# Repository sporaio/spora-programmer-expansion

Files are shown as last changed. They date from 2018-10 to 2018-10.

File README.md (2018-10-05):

# Spora Programmer Expansion

This is the repository of the Spora Programmer Expansion. Spora is coin-sized open source programmable board, equipped with multiple sensors, a powerful MCU and Bluetooth module to transmit your collected data.

With this board you can expand Spora's functioanlity into anything you want. Find out more about Spora at https://sporaio.com/

Spora's main board code is in this repository: https://github.com/sporaio/spora-board

## Contributors

This project is open source, under the BSD licence. You can contribute to it and be part of this great community.

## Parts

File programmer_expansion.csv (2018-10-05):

Refs | Desc | datasheet | digikey# | footprint | manf | manf# | value
C1 | 10uF 10% 16V Ceramic Capacitor X5R 0805 |  | 490-6473-1-ND | footprints:c_0805 | Murata Electronics North America | GRM21BR61C106KE15K | 10uF
C2 | 10uF 10% 16V Ceramic Capacitor X5R 0805 |  | 490-6473-1-ND | footprints:c_0805 | Murata Electronics North America | GRM21BR61C106KE15K | 10uF
C3 | 10uF 10% 16V Ceramic Capacitor X5R 0805 |  | 490-6473-1-ND | footprints:c_0805 | Murata Electronics North America | GRM21BR61C106KE15K | 10uF
C4 | 10uF 10% 16V Ceramic Capacitor X5R 0805 |  | 490-6473-1-ND | footprints:c_0805 | Murata Electronics North America | GRM21BR61C106KE15K | 10uF
C5 | 10uF 10% 16V Ceramic Capacitor X5R 0805 |  | 490-6473-1-ND | footprints:c_0805 | Murata Electronics North America | GRM21BR61C106KE15K | 10uF
C6 | 10uF 10% 16V Ceramic Capacitor X5R 0805 |  | 490-6473-1-ND | footprints:c_0805 | Murata Electronics North America | GRM21BR61C106KE15K | 10uF
C7 | 0.10uF 10% 16V Ceramic Capacitor X7R 0805 |  | 490-1683-1-ND | footprints:c_0805 | Murata Electronics North America | GRM219R71C104KA01D | 0.1uF
CON1 | Power Barrel Connector Jack 0.70mm ID (0.028), 2.35mm OD (0.093) EIAJ-1 Surface Mount, Right Angle |  | CP-038PJCT-ND | footprints:Pj-38-smt | CUI Inc. | PJ-038-SMT-TR | BARREL_JACK
CON2 | Pad de coneccion para una eventual bateria |  |  | footprints:GS2 |  |  | TP1
CON3 | 10 Positions Header, Unshrouded Connector 0.100 (2.54mm) Through Hole Tin |  | 609-3243-ND | Pin_Headers:Pin_Header_Straight_2x05 | Amphenol FCI | 67997-410HLF | SWD_BT
CON4 | 10 Positions Header, Unshrouded Connector 0.100 (2.54mm) Through Hole Tin |  | 609-3243-ND | Pin_Headers:Pin_Header_Straight_2x05 | Amphenol FCI | 67997-410HLF | SWD_MCU
D1 | Red 645nm LED Indication - Discrete 1.8V 0805 (2012 Metric) |  | 475-1415-1-ND | footprints:LED-0805 | OSRAM Opto Semiconductors Inc. | LH R974-LP-1 | Led
D2 | Red 645nm LED Indication - Discrete 1.8V 0805 (2012 Metric) |  | 475-1415-1-ND | footprints:LED-0805 | OSRAM Opto Semiconductors Inc. | LH R974-LP-1 | Led
G1 | Logo INTI |  |  | footprints:LOGO_INTI |  |  | LOGO_INTI
J1 | 10 Position Connector Receptacle, Center Strip Contacts Surface Mount Gold |  | H11719CT-ND | footprints:df12(3.0)-10ds-0.5v | Hirose Electric Co Ltd | DF12B3.0-10DS-0.5V86 | DF12B-3.0-10DS-0.5V-81
R1 | RES SMD 270 OHM 1% 1/8W 0805 |  | 311-270CRCT-ND | footprints:r_0805 | Yageo | RC0805FR-07270RL | 270
R2 | RES SMD 470 OHM 1% 1/8W 0805 |  | 311-470CRCT-ND | footprints:r_0805 | Yageo | RC0805FR-07470RL | 470
R3 | RES SMD 1.2K OHM 1% 1/8W 0805 |  | 311-1.20KCRCT-ND | footprints:r_0805 | Yageo | RC0805FR-071K2L | 1,2k
R4 | RES SMD 280 OHM 1% 1/8W 0805 |  | 311-280CRCT-ND | footprints:r_0805 | Yageo | RC0805FR-07280RL | 280
R5 | RES SMD 10K OHM 5% 1/4W 0805 |  | RPC0805JT10K0DKR-ND | footprints:r_0805 | Stackpole Electronics Inc. | RPC0805JT10K0 | 10K
R6 | RES SMD 4.7K OHM 5% 1/2W 0805 |  | P16962CT-ND | footprints:r_0805 | Panasonic Electronic Components | ERJ-P6WJ472V | 4,7K
R7 | RES SMD 4.7K OHM 5% 1/2W 0805 |  | P16962CT-ND | footprints:r_0805 | Panasonic Electronic Components | ERJ-P6WJ472V | 4,7K
R8 | RES SMD 4.7K OHM 5% 1/2W 0805 |  | P16962CT-ND | footprints:r_0805 | Panasonic Electronic Components | ERJ-P6WJ472V | 4K7
SW1 | Tactile Switch SPST-NO Top Actuated Surface Mount |  | SW1143CT-ND | footprints:B3U_1000PB | Omron Electronics Inc-EMC Div | B3U-1000P-B | SIDE_SW
SW2 | Tactile Switch SPST-NO Top Actuated Surface Mount |  | SW1143CT-ND | footprints:B3U_1000PB | Omron Electronics Inc-EMC Div | B3U-1000P-B | SIDE_SW
U1 | Linear Voltage Regulator IC Positive Adjustable 1 Output 1.25 V 13.8 V 800mA SOT-223 |  | LM1117MPX-ADJ/NOPBCT-ND | footprints:sot223 | Texas Instruments | LM1117MPX-ADJ/NOPB | LM1117
U2 | Linear Voltage Regulator IC Positive Adjustable 1 Output 1.25 V 13.8 V 800mA SOT-223 |  | LM1117MPX-ADJ/NOPBCT-ND | footprints:sot223 | Texas Instruments | LM1117MPX-ADJ/NOPB | LM1117
C10 | CAP CER 0.1UF 16V X7R 0805 |  | 490-1683-1-ND | footprints:c_0805 | Murata Electronics North America | GRM219R71C104KA01D | 0.1uF
C11 | CAP CER 0.1UF 16V X7R 0805 |  | 490-1683-1-ND | footprints:c_0805 | Murata Electronics North America | GRM219R71C104KA01D | 0.1uF
C8 | CAP CER 0.1UF 16V X7R 0805 |  | 490-1683-1-ND | footprints:c_0805 | Murata Electronics North America | GRM219R71C104KA01D | 0.1uF
C9 | CAP CER 0.1UF 16V X7R 0805 |  | 490-1683-1-ND | footprints:c_0805 | Murata Electronics North America | GRM219R71C104KA01D | 0.1uF

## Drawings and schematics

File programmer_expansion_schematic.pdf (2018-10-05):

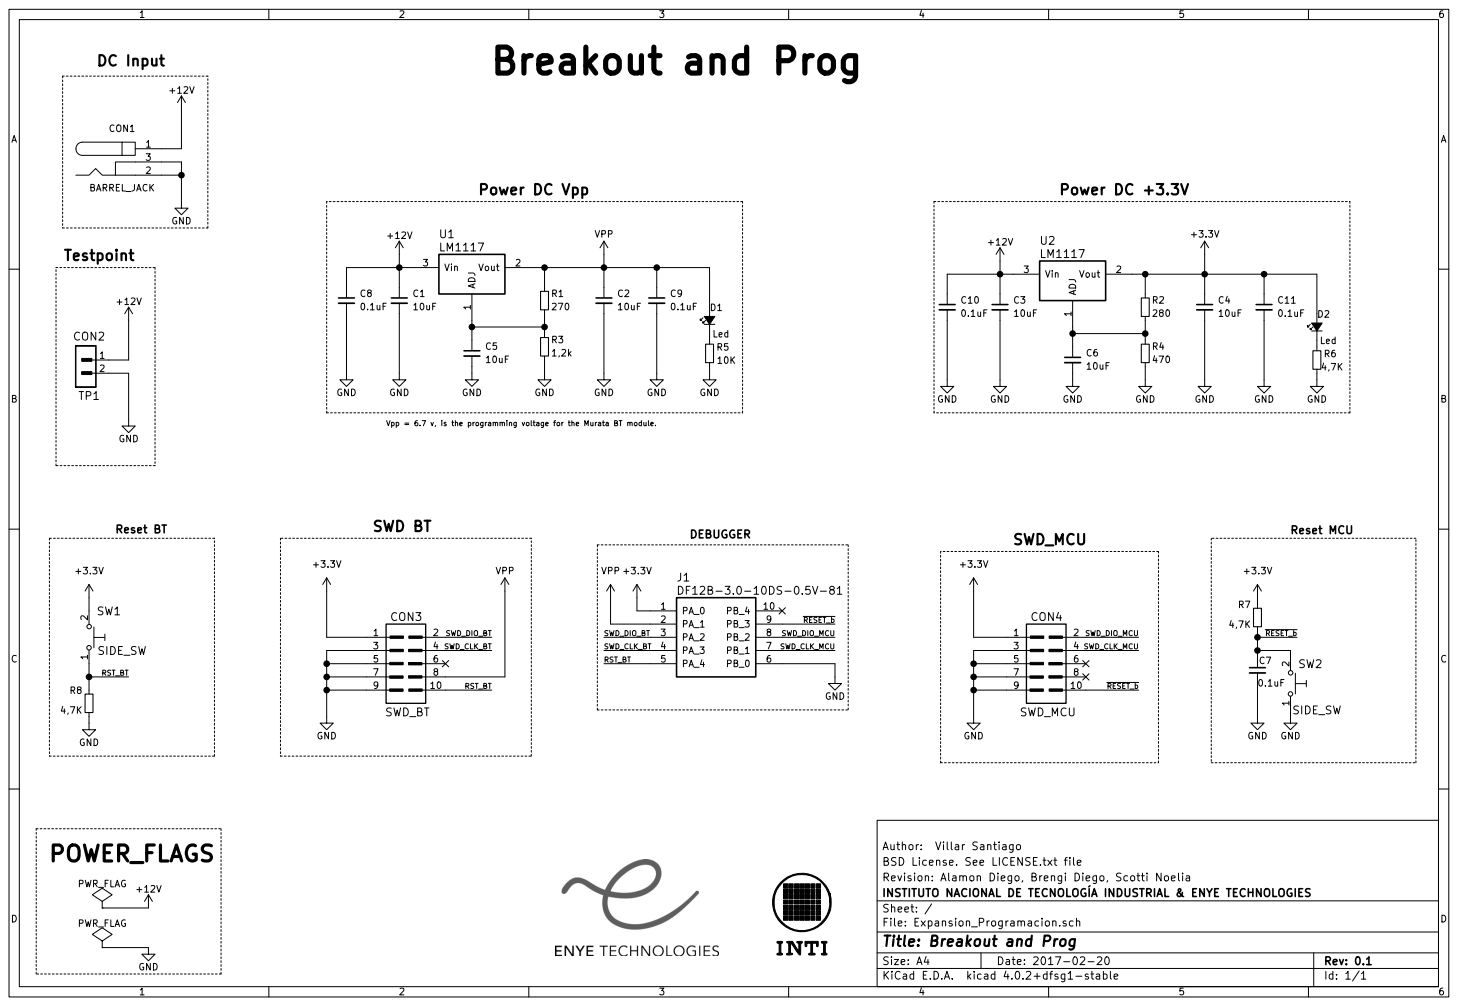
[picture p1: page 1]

3 CON1 BARREL_JACK

Revision: Alamon Diego, Brengi Diego, Scotti Noelia BSD License. See LICENSE.txt file Author: Villar Santiago PWR_FLAG

INSTITUTO NACIONAL DE TECNOLOGÍA INDUSTRIAL & ENYE TECHNOLOGIES
File: Expansion_Programacion.sch Sheet: /
Id: 1/1 Title: Breakout and Prog

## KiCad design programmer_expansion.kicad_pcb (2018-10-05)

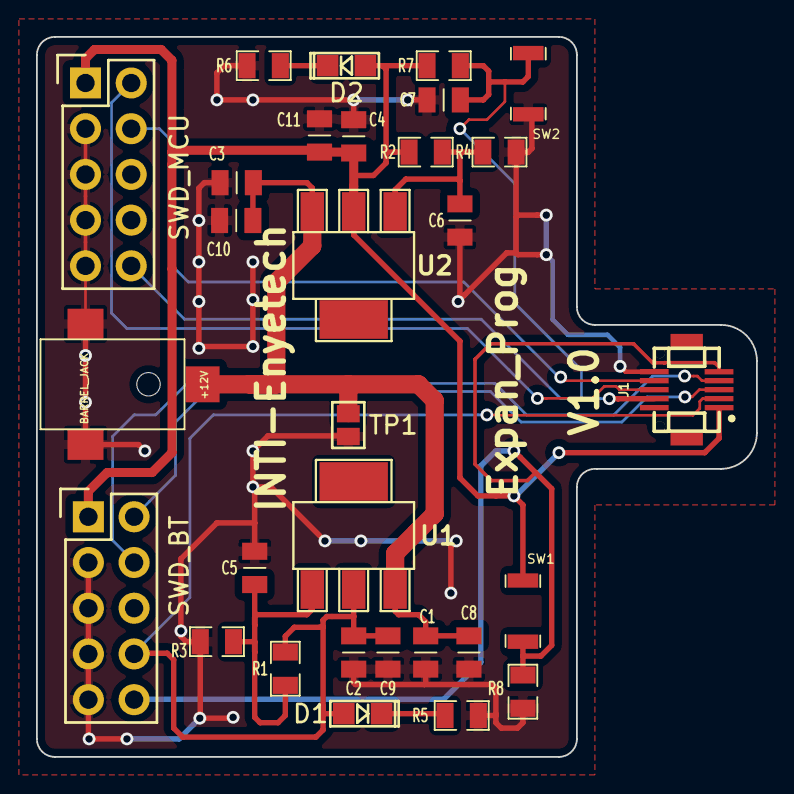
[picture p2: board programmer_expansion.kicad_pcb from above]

Board: 2 copper layers, 40.0 x 40.0 mm, 30 parts (0 on the bottom side), 14 nets.

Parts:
+12V: BARREL_JACK; Pj-38-smt
C1, C2, C3, C4, C5, C6: 10uF; c_0805
C7, C8, C9, C10, C11: 0.1uF; c_0805
D1, D2: Led; LED-0805
J1: DF12B-3.0-10DS-0.5V-81; df12(3.0)-10ds-0.5v
R1: 270; r_0805
R2: 470; r_0805
R3: 1,2k; r_0805
R4: 280; r_0805
R5: 10K; r_0805
R6, R7: 4,7K; r_0805
R8: 4K7; r_0805
SW1, SW2: SIDE_SW; B3U_1000PB
SWD_BT: SWD_BT; Pin_Header_Straight_2x05
SWD_MCU: SWD_MCU; Pin_Header_Straight_2x05
TP1: TP1; GS2
U1, U2: LM1117; sot223

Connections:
+3V3: C4.1, C11.1, D2.2, J1.1, R2.1, R7.2, SW1.2, SWD_BT.1, SWD_MCU.1, U2.2
+12V: +12V.1, C1.1, C3.1, C8.1, C10.1, TP1.1, U1.3, U2.3
/RST_BT: J1.5, R8.2, SW1.1, SWD_BT.10
/SWD_CLK_BT: J1.4, SWD_BT.4
/SWD_CLK_MCU: J1.7, SWD_MCU.4
/SWD_DIO_BT: J1.3, SWD_BT.2
/SWD_DIO_MCU: J1.8, SWD_MCU.2
/~RESET_b: C7.1, J1.9, R7.1, SW2.2, SWD_MCU.10
GND: +12V.2, +12V.3, C1.2, C2.2, C3.2, C4.2, C5.2, C6.2, C7.2, C8.2, C9.2, C10.2, C11.2, J1.6, R3.2, R4.2, R5.1, R6.1, R8.1, SW2.1, SWD_BT.3, SWD_BT.5, SWD_BT.7, SWD_BT.9, SWD_MCU.3, SWD_MCU.5, SWD_MCU.7, SWD_MCU.9, TP1.2
unnamed: C5.1, R1.2, R3.1, U1.1
unnamed: C6.1, R2.2, R4.1, U2.1
unnamed: D1.1, R5.2
unnamed: D2.1, R6.2
VPP: C2.1, C9.1, D1.2, J1.2, R1.1, SWD_BT.8, U1.2
